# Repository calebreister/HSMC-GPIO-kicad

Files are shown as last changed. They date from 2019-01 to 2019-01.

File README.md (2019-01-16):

# HSMC-GPIO-kicad

This is a project created to test my new [HSMC Card KiCad footprints](https://github.com/KiCad/kicad-footprints/pulls?page=1&q=is%3Apr+is%3Aopen). It is based loosely on the [Terasis HSTC-GPIO Card](https://www.terasic.com.tw/cgi-bin/page/archive.pl?Language=English&No=322). In small quantities, the cost is comparable to the HSTC-GPIO Card.

## Features
- 40 GPIO pins
- Protection diodes and series resistors
- Power supply terminals
- Buffered I2C port with selectable voltage

## License
<br /><span xmlns:dct="http://purl.org/dc/terms/" property="dct:title">HSMC-GPIO-kicad</span> by <a xmlns:cc="http://creativecommons.org/ns#" href="https://github.com/calebreister/" property="cc:attributionName" rel="cc:attributionURL">Caleb Reister</a> is licensed under a <a rel="license" href="http://creativecommons.org/licenses/by-sa/4.0/">Creative Commons Attribution-ShareAlike 4.0 International License</a>.

## Pictures
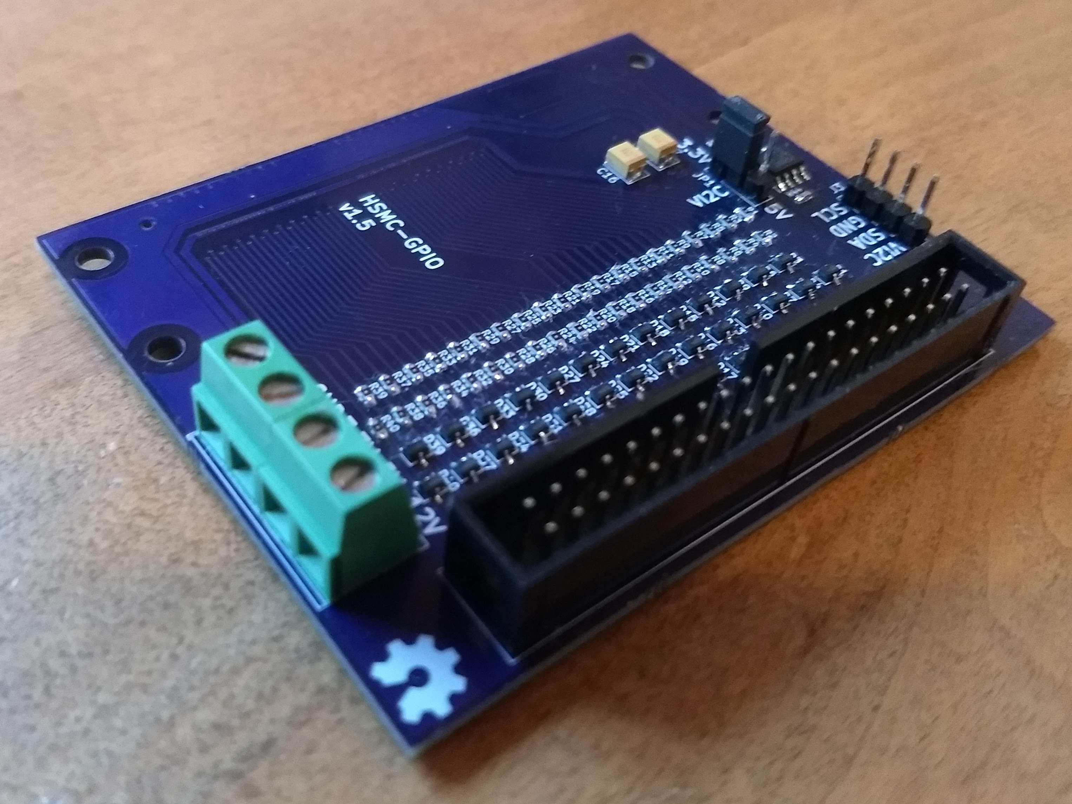
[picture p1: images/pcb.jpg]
Assembled PCB


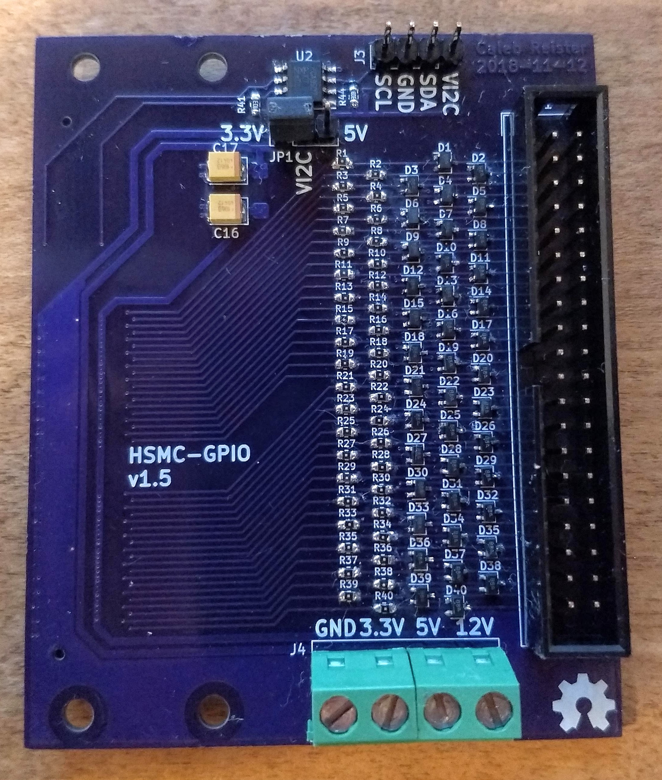
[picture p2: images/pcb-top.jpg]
PCB Top


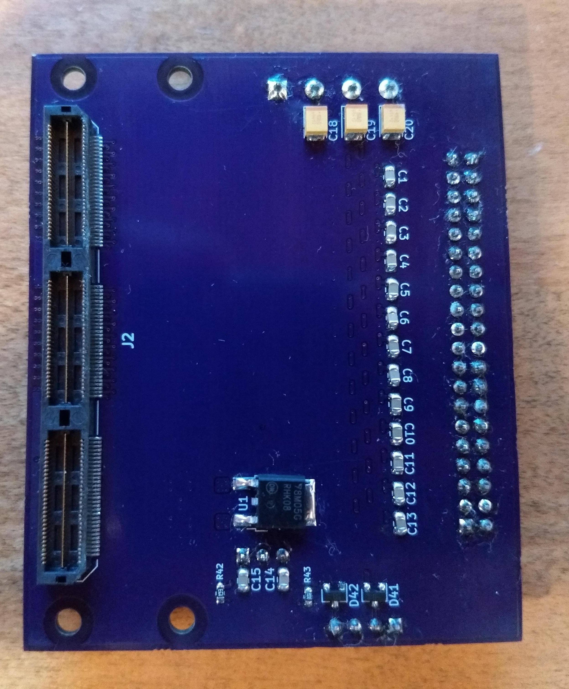
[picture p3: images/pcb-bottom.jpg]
PCB Bottom


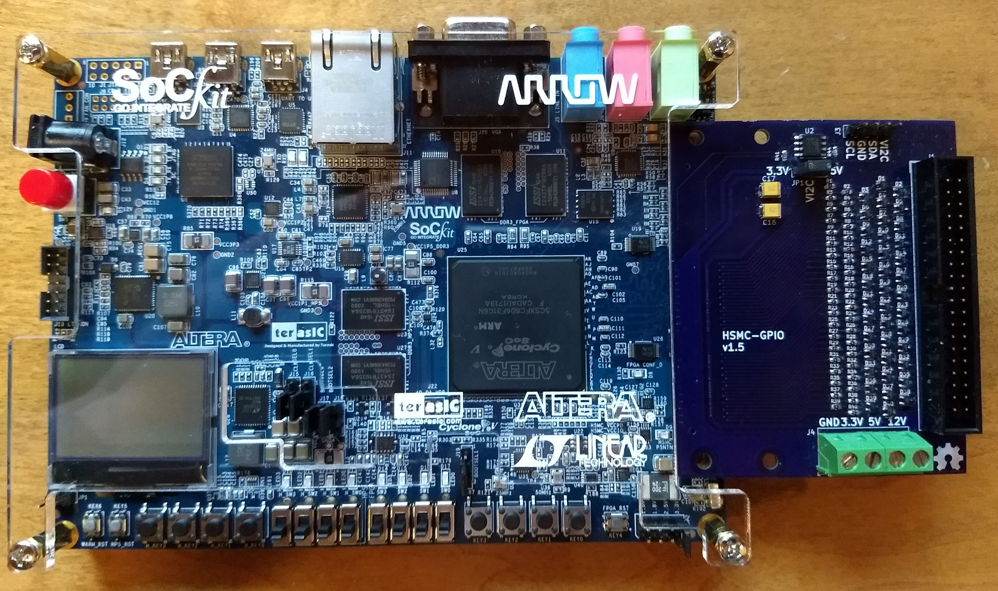
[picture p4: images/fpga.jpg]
PCB Attached to an FPGA board


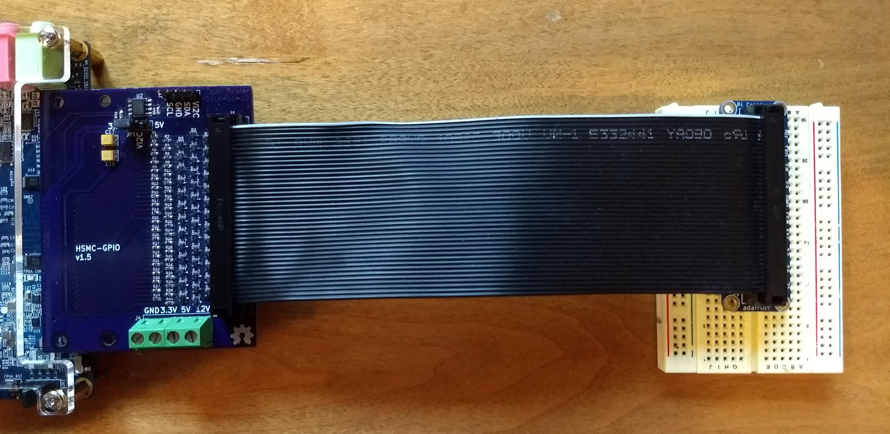
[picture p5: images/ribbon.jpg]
40-pin ribbon cable


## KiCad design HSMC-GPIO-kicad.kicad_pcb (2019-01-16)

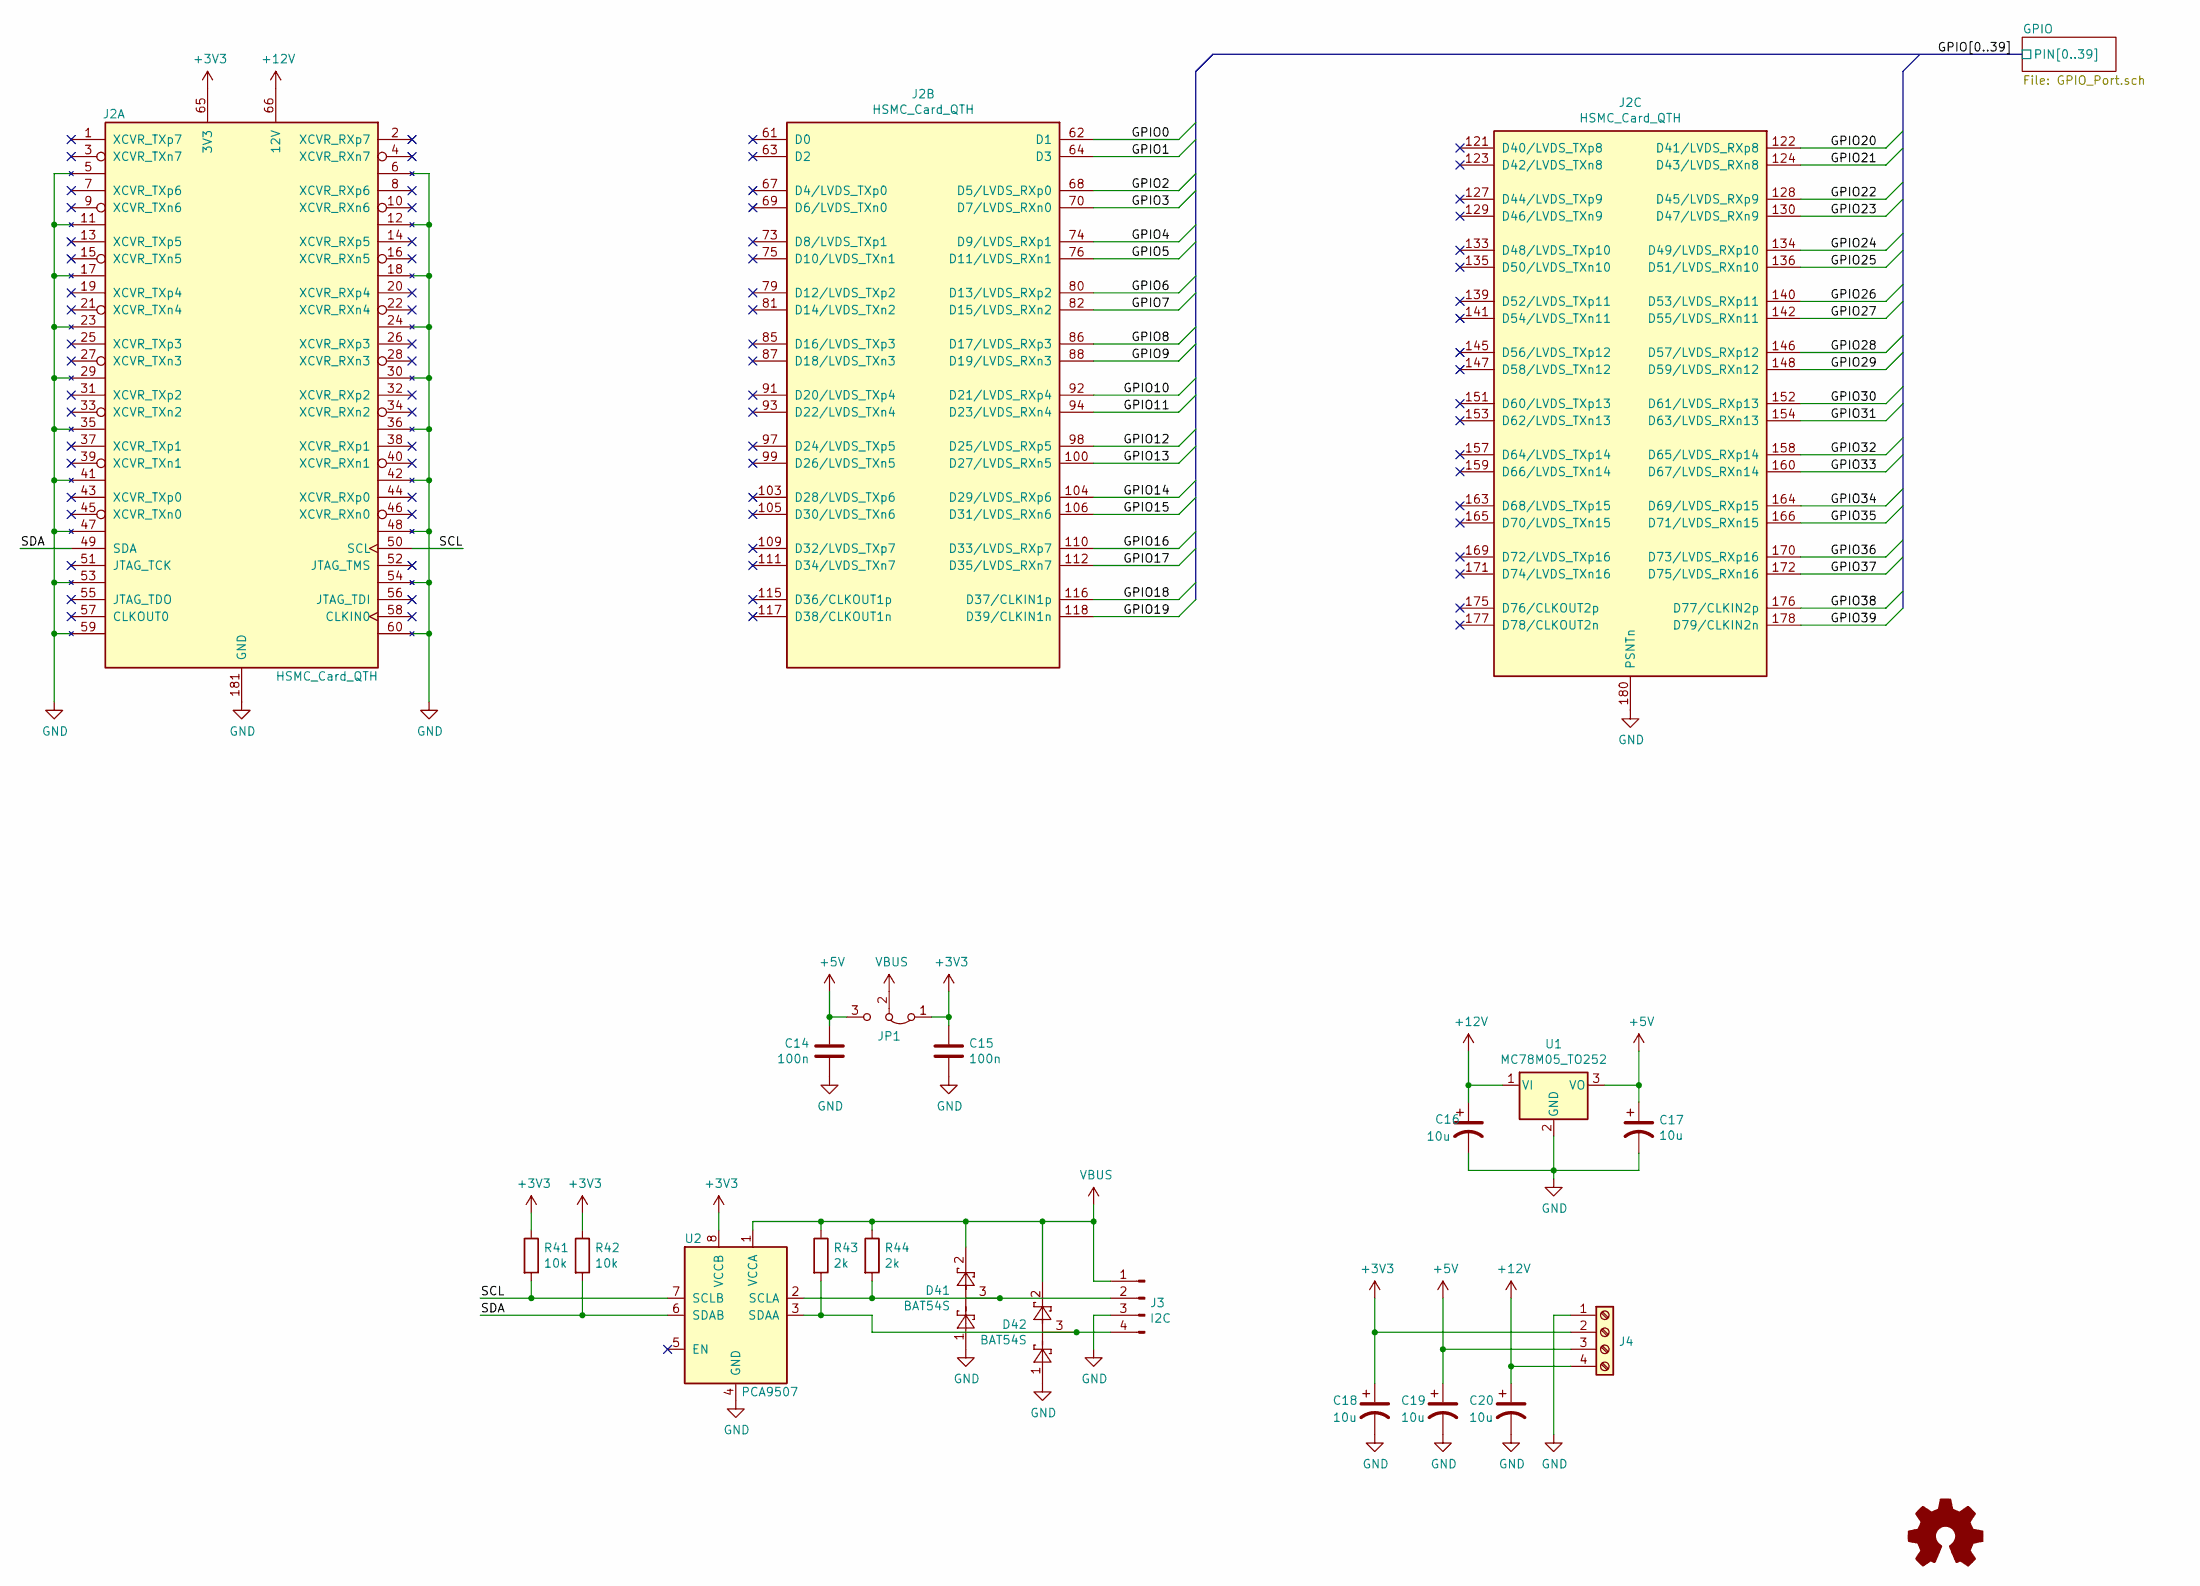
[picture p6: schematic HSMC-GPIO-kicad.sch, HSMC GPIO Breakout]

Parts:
C14, C15: 100n; C_0805_2012Metric
C16, C17, C18, C19, C20: 10u; CP_EIA-3528-21_Kemet-B
D41, D42: BAT54S; SOT-23
J2: HSMC_Card_QTH; Samtec_HSMC_Card_QTH-090-01-x-D-A_3.076x0.932in_P0.5mm_Vert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
J3: I2C; PinHeader_1x04_P2.54mm_Vertical
J4: Screw_Terminal_01x04; TerminalBlock_bornier-4_P5.08mm
JP1: Jumper_3_Bridged12; PinHeader_1x03_P2.54mm_Vertical
LOGO1: Logo_Open_Hardware_Small; OSHW-Symbol_6.7x6mm_SilkScreen
R41, R42: 10k; R_0603_1608Metric
R43, R44: 2k; R_0603_1608Metric
U1: MC78M05_TO252; TO-252-2
U2: PCA9507; SOIC-8_3.9x4.9mm_P1.27mm

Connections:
+3V3: C15.2, C18.1, J2.65 (3V3), J2.71 (3V3), J2.77 (3V3), J2.83 (3V3), J2.89 (3V3), J2.95 (3V3), J2.101 (3V3), J2.107 (3V3), J2.113 (3V3), J2.119 (3V3), J2.125 (3V3), J2.131 (3V3), J2.137 (3V3), J2.143 (3V3), J2.149 (3V3), J2.155 (3V3), J2.161 (3V3), J2.167 (3V3), J2.173 (3V3), J2.179 (3V3), J4.2, JP1.1 (A), R41.1, R42.1, U2.8 (VCCB); also elsewhere on the board
+5V: C14.2, C17.1, C19.1, J4.3, JP1.3 (B), U1.3 (VO)
+12V: C16.1, C20.1, J2.66 (12V), J2.72 (12V), J2.78 (12V), J2.84 (12V), J2.90 (12V), J2.96 (12V), J2.102 (12V), J2.108 (12V), J2.114 (12V), J2.120 (12V), J2.126 (12V), J2.132 (12V), J2.138 (12V), J2.144 (12V), J2.150 (12V), J2.156 (12V), J2.162 (12V), J2.168 (12V), J2.174 (12V), J4.4, U1.1 (VI)
/GPIO0: J2.62 (D1); also elsewhere on the board
/GPIO1: J2.64 (D3); also elsewhere on the board
/GPIO2: J2.68 (D5/LVDS_RXp0); also elsewhere on the board
/GPIO3: J2.70 (D7/LVDS_RXn0); also elsewhere on the board
/GPIO4: J2.74 (D9/LVDS_RXp1); also elsewhere on the board
/GPIO5: J2.76 (D11/LVDS_RXn1); also elsewhere on the board
/GPIO6: J2.80 (D13/LVDS_RXp2); also elsewhere on the board
/GPIO7: J2.82 (D15/LVDS_RXn2); also elsewhere on the board
/GPIO8: J2.86 (D17/LVDS_RXp3); also elsewhere on the board
/GPIO9: J2.88 (D19/LVDS_RXn3); also elsewhere on the board
/GPIO10: J2.92 (D21/LVDS_RXp4); also elsewhere on the board
/GPIO11: J2.94 (D23/LVDS_RXn4); also elsewhere on the board
/GPIO12: J2.98 (D25/LVDS_RXp5); also elsewhere on the board
/GPIO13: J2.100 (D27/LVDS_RXn5); also elsewhere on the board
/GPIO14: J2.104 (D29/LVDS_RXp6); also elsewhere on the board
/GPIO15: J2.106 (D31/LVDS_RXn6); also elsewhere on the board
/GPIO16: J2.110 (D33/LVDS_RXp7); also elsewhere on the board
/GPIO17: J2.112 (D35/LVDS_RXn7); also elsewhere on the board
/GPIO18: J2.116 (D37/CLKIN1p); also elsewhere on the board
/GPIO19: J2.118 (D39/CLKIN1n); also elsewhere on the board
/GPIO20: J2.122 (D41/LVDS_RXp8); also elsewhere on the board
/GPIO21: J2.124 (D43/LVDS_RXn8); also elsewhere on the board
/GPIO22: J2.128 (D45/LVDS_RXp9); also elsewhere on the board
/GPIO23: J2.130 (D47/LVDS_RXn9); also elsewhere on the board
/GPIO24: J2.134 (D49/LVDS_RXp10); also elsewhere on the board
/GPIO25: J2.136 (D51/LVDS_RXn10); also elsewhere on the board
/GPIO26: J2.140 (D53/LVDS_RXp11); also elsewhere on the board
/GPIO27: J2.142 (D55/LVDS_RXn11); also elsewhere on the board
/GPIO28: J2.146 (D57/LVDS_RXp12); also elsewhere on the board
/GPIO29: J2.148 (D59/LVDS_RXn12); also elsewhere on the board
/GPIO30: J2.152 (D61/LVDS_RXp13); also elsewhere on the board
/GPIO31: J2.154 (D63/LVDS_RXn13); also elsewhere on the board
/GPIO32: J2.158 (D65/LVDS_RXp14); also elsewhere on the board
/GPIO33: J2.160 (D67/LVDS_RXn14); also elsewhere on the board
/GPIO34: J2.164 (D69/LVDS_RXp15); also elsewhere on the board
/GPIO35: J2.166 (D71/LVDS_RXn15); also elsewhere on the board
/GPIO36: J2.170 (D73/LVDS_RXp16); also elsewhere on the board
/GPIO37: J2.172 (D75/LVDS_RXn16); also elsewhere on the board
/GPIO38: J2.176 (D77/CLKIN2p); also elsewhere on the board
/GPIO39: J2.178 (D79/CLKIN2n); also elsewhere on the board
/SCL: J2.50 (SCL), R41.2, U2.7 (SCLB)
/SDA: J2.49 (SDA), R42.2, U2.6 (SDAB)
GND: C14.1, C15.1, C16.2, C17.2, C18.2, C19.2, C20.2, D41.1, D42.1, J2.5, J2.6, J2.11, J2.12, J2.17, J2.18, J2.23, J2.24, J2.29, J2.30, J2.35, J2.36, J2.41, J2.42, J2.47, J2.48, J2.53, J2.54, J2.59, J2.60, J2.180 (PSNTn), J2.181 (GND), J2.182 (GND), J2.183 (GND), J2.184 (GND), J2.185 (GND), J2.186 (GND), J2.187 (GND), J2.188 (GND), J2.189 (GND), J2.190 (GND), J2.191 (GND), J2.192 (GND), J3.3, J4.1, U1.2 (GND), U2.4 (GND); also elsewhere on the board
unnamed: D41.3, J3.2, R44.2, U2.2 (SCLA)
unnamed: D42.3, J3.4, R43.2, U2.3 (SDAA)
VBUS: D41.2, D42.2, J3.1, JP1.2 (C), R43.1, R44.1, U2.1 (VCCA)

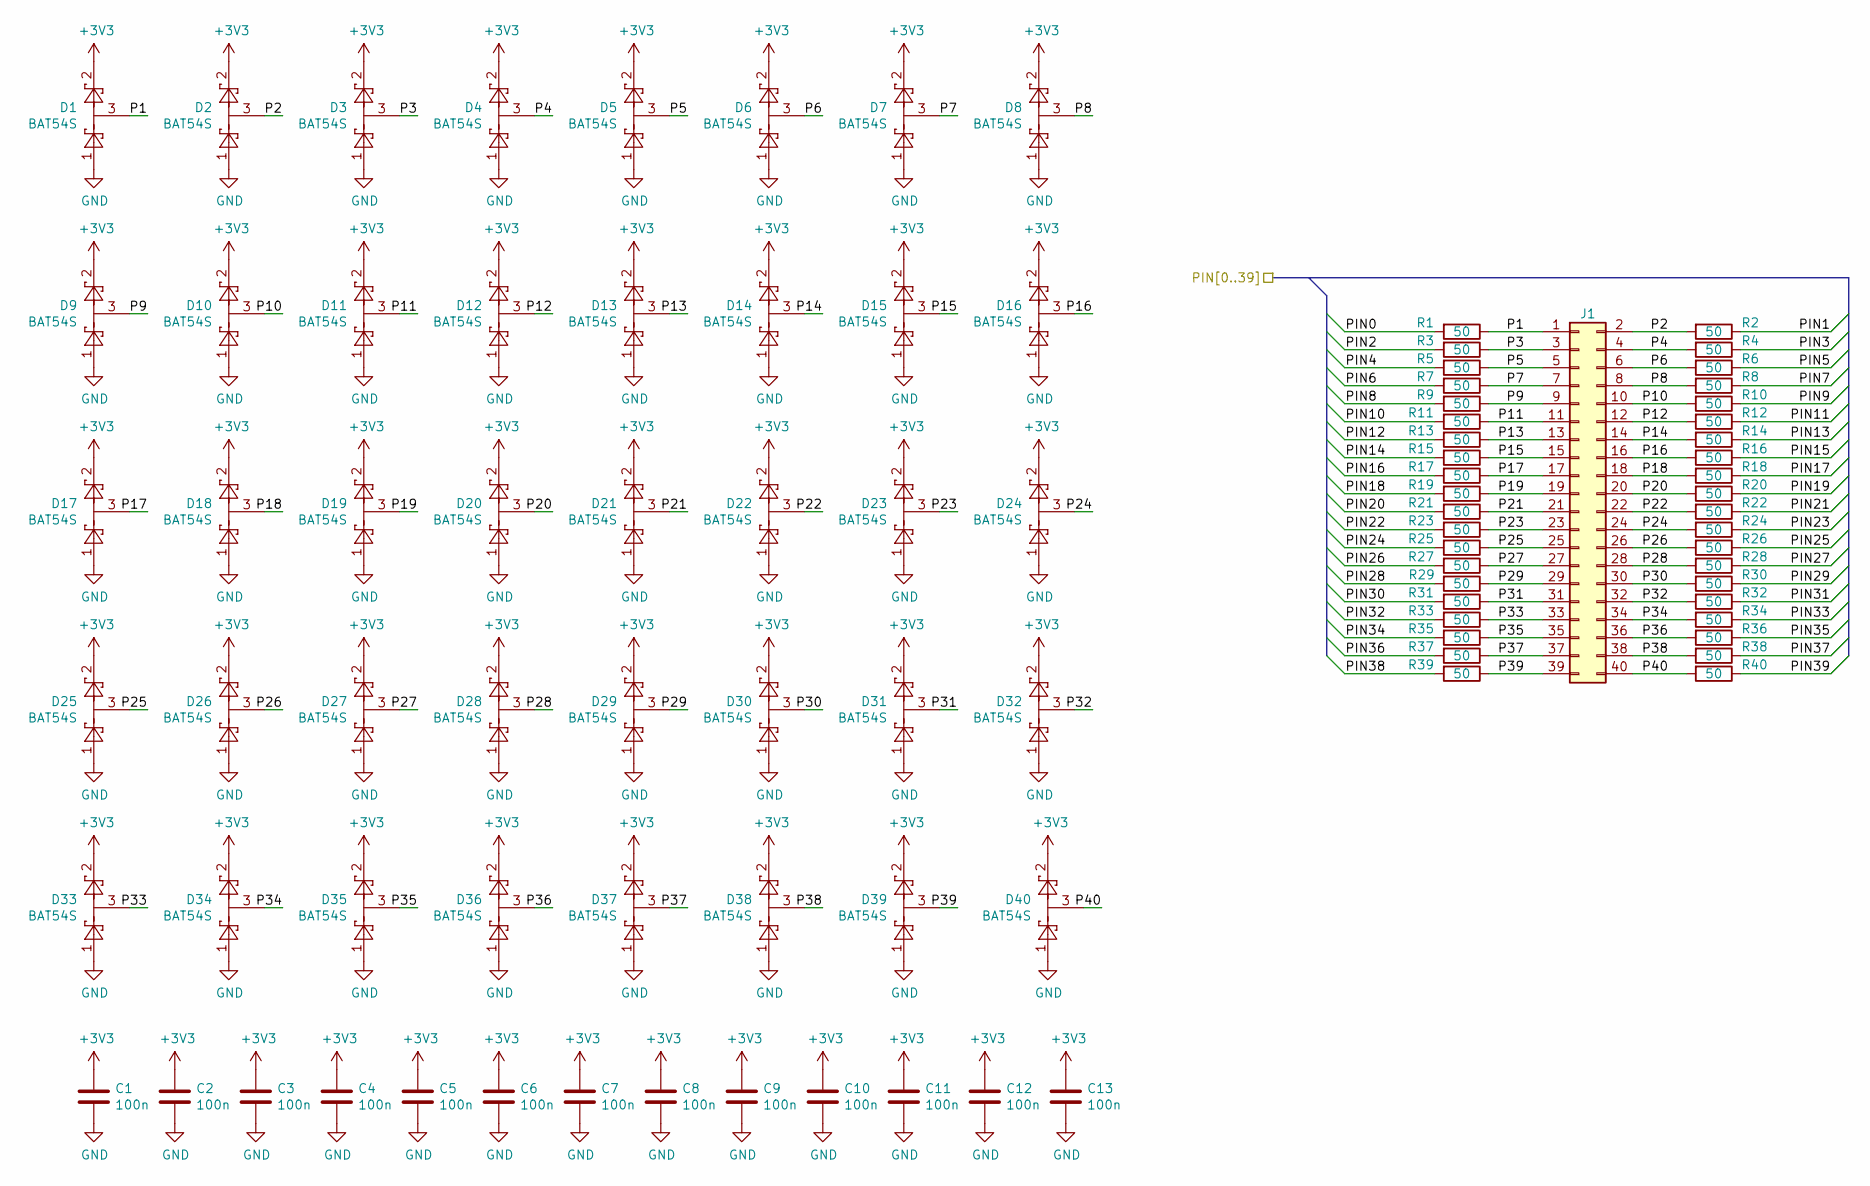
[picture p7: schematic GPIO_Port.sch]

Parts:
C1, C2, C3, C4, C5, C6, C7, C8, C9, C10, C11, C12, C13: 100n; C_0805_2012Metric
D1, D2, D3, D4, D5, D6, D7, D8, D9, D10, D11, D12, D13, D14, D15, D16, D17, D18, D19, D20, D21, D22, D23, D24, D25, D26, D27, D28, D29, D30, D31, D32, D33, D34, D35, D36, D37, D38, D39, D40: BAT54S; SOT-323_SC-70
J1: Conn_02x20_Odd_Even; IDC-Header_2x20_P2.54mm_Vertical
R1, R2, R3, R4, R5, R6, R7, R8, R9, R10, R11, R12, R13, R14, R15, R16, R17, R18, R19, R20, R21, R22, R23, R24, R25, R26, R27, R28, R29, R30, R31, R32, R33, R34, R35, R36, R37, R38, R39, R40: 50; R_0603_1608Metric

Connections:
+3V3: C1.1, C2.1, C3.1, C4.1, C5.1, C6.1, C7.1, C8.1, C9.1, C10.1, C11.1, C12.1, C13.1, D1.2, D2.2, D3.2, D4.2, D5.2, D6.2, D7.2, D8.2, D9.2, D10.2, D11.2, D12.2, D13.2, D14.2, D15.2, D16.2, D17.2, D18.2, D19.2, D20.2, D21.2, D22.2, D23.2, D24.2, D25.2, D26.2, D27.2, D28.2, D29.2, D30.2, D31.2, D32.2, D33.2, D34.2, D35.2, D36.2, D37.2, D38.2, D39.2, D40.2; also elsewhere on the board
/GPIO0: R1.2; also elsewhere on the board
/GPIO1: R2.1; also elsewhere on the board
/GPIO2: R3.2; also elsewhere on the board
/GPIO3: R4.1; also elsewhere on the board
/GPIO4: R5.2; also elsewhere on the board
/GPIO5: R6.1; also elsewhere on the board
/GPIO6: R7.2; also elsewhere on the board
/GPIO7: R8.1; also elsewhere on the board
/GPIO8: R9.2; also elsewhere on the board
/GPIO9: R10.1; also elsewhere on the board
/GPIO10: R11.2; also elsewhere on the board
/GPIO11: R12.1; also elsewhere on the board
/GPIO12: R13.2; also elsewhere on the board
/GPIO13: R14.1; also elsewhere on the board
/GPIO14: R15.2; also elsewhere on the board
/GPIO15: R16.1; also elsewhere on the board
/GPIO16: R17.2; also elsewhere on the board
/GPIO17: R18.1; also elsewhere on the board
/GPIO18: R19.2; also elsewhere on the board
/GPIO19: R20.1; also elsewhere on the board
/GPIO20: R21.2; also elsewhere on the board
/GPIO21: R22.1; also elsewhere on the board
/GPIO22: R23.2; also elsewhere on the board
/GPIO23: R24.1; also elsewhere on the board
/GPIO24: R25.2; also elsewhere on the board
/GPIO25: R26.1; also elsewhere on the board
/GPIO26: R27.2; also elsewhere on the board
/GPIO27: R28.1; also elsewhere on the board
/GPIO28: R29.2; also elsewhere on the board
/GPIO29: R30.1; also elsewhere on the board
/GPIO30: R31.2; also elsewhere on the board
/GPIO31: R32.1; also elsewhere on the board
/GPIO32: R33.2; also elsewhere on the board
/GPIO33: R34.1; also elsewhere on the board
/GPIO34: R35.2; also elsewhere on the board
/GPIO35: R36.1; also elsewhere on the board
/GPIO36: R37.2; also elsewhere on the board
/GPIO37: R38.1; also elsewhere on the board
/GPIO38: R39.2; also elsewhere on the board
/GPIO39: R40.1; also elsewhere on the board
/GPIO/P1: D1.3, J1.1, R1.1
/GPIO/P2: D2.3, J1.2, R2.2
/GPIO/P3: D3.3, J1.3, R3.1
/GPIO/P4: D4.3, J1.4, R4.2
/GPIO/P5: D5.3, J1.5, R5.1
/GPIO/P6: D6.3, J1.6, R6.2
/GPIO/P7: D7.3, J1.7, R7.1
/GPIO/P8: D8.3, J1.8, R8.2
/GPIO/P9: D9.3, J1.9, R9.1
/GPIO/P10: D10.3, J1.10, R10.2
/GPIO/P11: D11.3, J1.11, R11.1
/GPIO/P12: D12.3, J1.12, R12.2
/GPIO/P13: D13.3, J1.13, R13.1
/GPIO/P14: D14.3, J1.14, R14.2
/GPIO/P15: D15.3, J1.15, R15.1
/GPIO/P16: D16.3, J1.16, R16.2
/GPIO/P17: D17.3, J1.17, R17.1
/GPIO/P18: D18.3, J1.18, R18.2
/GPIO/P19: D19.3, J1.19, R19.1
/GPIO/P20: D20.3, J1.20, R20.2
/GPIO/P21: D21.3, J1.21, R21.1
/GPIO/P22: D22.3, J1.22, R22.2
/GPIO/P23: D23.3, J1.23, R23.1
/GPIO/P24: D24.3, J1.24, R24.2
/GPIO/P25: D25.3, J1.25, R25.1
/GPIO/P26: D26.3, J1.26, R26.2
/GPIO/P27: D27.3, J1.27, R27.1
/GPIO/P28: D28.3, J1.28, R28.2
/GPIO/P29: D29.3, J1.29, R29.1
/GPIO/P30: D30.3, J1.30, R30.2
/GPIO/P31: D31.3, J1.31, R31.1
/GPIO/P32: D32.3, J1.32, R32.2
/GPIO/P33: D33.3, J1.33, R33.1
/GPIO/P34: D34.3, J1.34, R34.2
/GPIO/P35: D35.3, J1.35, R35.1
/GPIO/P36: D36.3, J1.36, R36.2
/GPIO/P37: D37.3, J1.37, R37.1
/GPIO/P38: D38.3, J1.38, R38.2
/GPIO/P39: D39.3, J1.39, R39.1
/GPIO/P40: D40.3, J1.40, R40.2
GND: C1.2, C2.2, C3.2, C4.2, C5.2, C6.2, C7.2, C8.2, C9.2, C10.2, C11.2, C12.2, C13.2, D1.1, D2.1, D3.1, D4.1, D5.1, D6.1, D7.1, D8.1, D9.1, D10.1, D11.1, D12.1, D13.1, D14.1, D15.1, D16.1, D17.1, D18.1, D19.1, D20.1, D21.1, D22.1, D23.1, D24.1, D25.1, D26.1, D27.1, D28.1, D29.1, D30.1, D31.1, D32.1, D33.1, D34.1, D35.1, D36.1, D37.1, D38.1, D39.1, D40.1; also elsewhere on the board

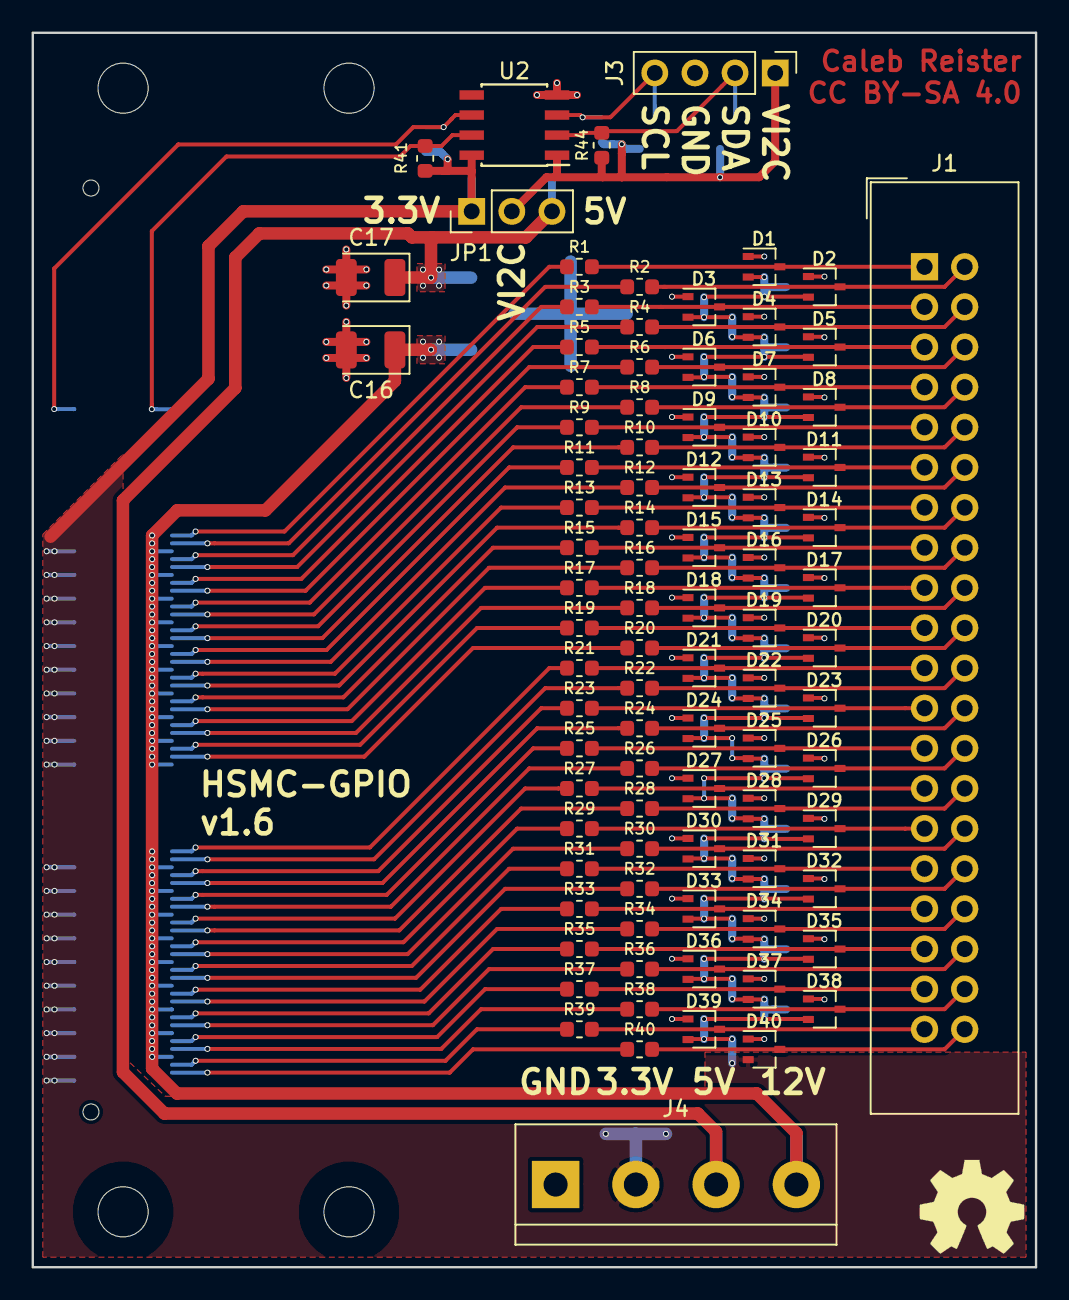
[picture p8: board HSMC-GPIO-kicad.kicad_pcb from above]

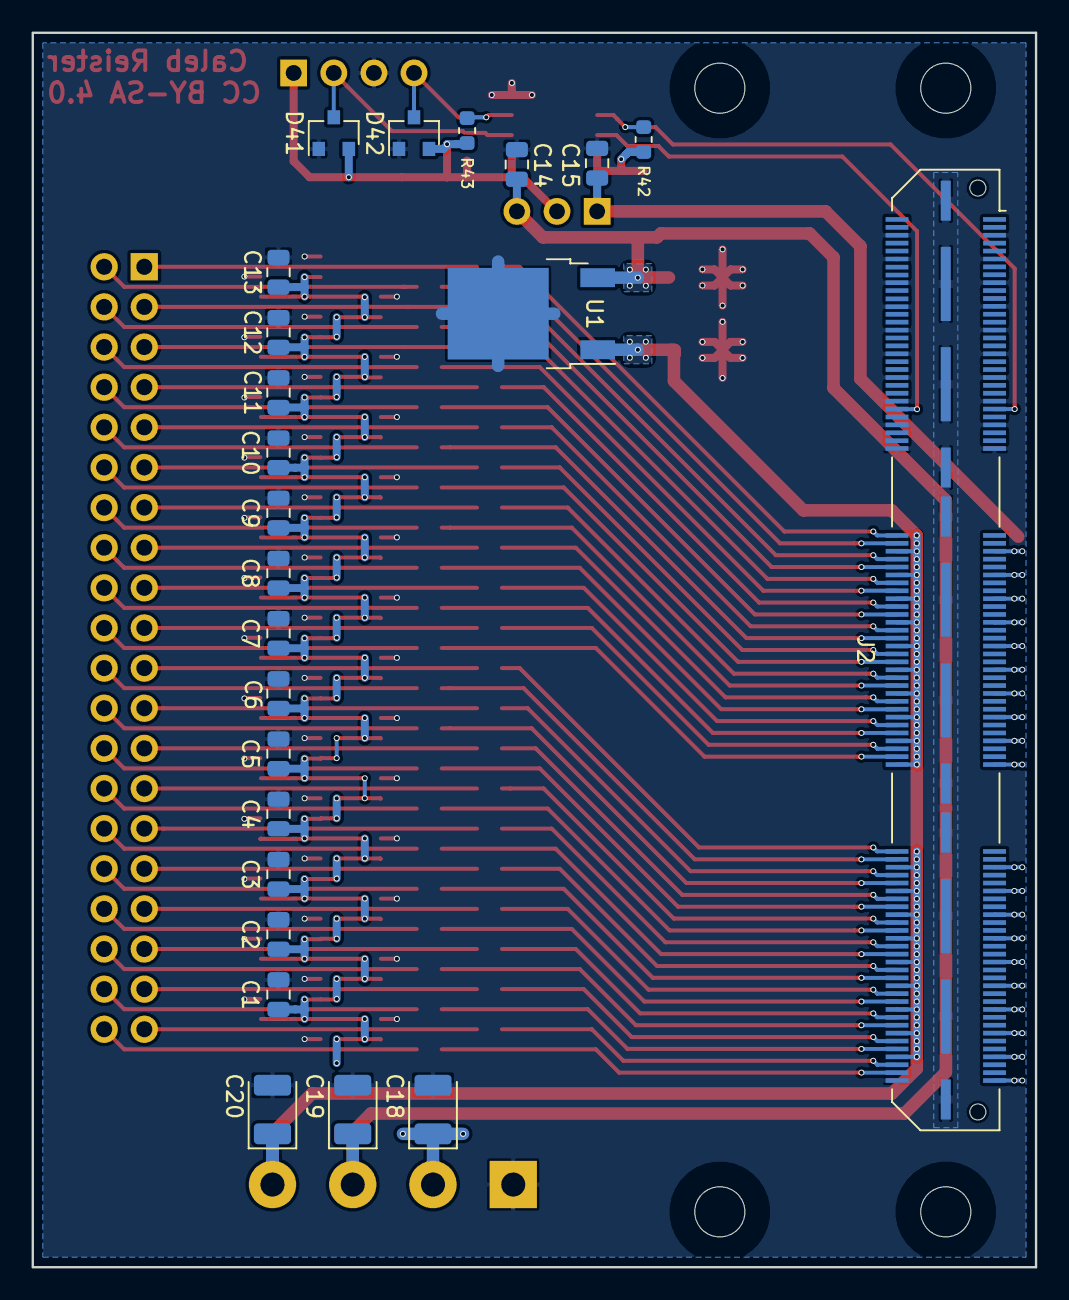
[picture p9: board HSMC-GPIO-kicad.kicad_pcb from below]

Board: 2 copper layers, 63.5 x 78.1 mm, 114 parts (24 on the bottom side), 89 nets.

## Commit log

2018-09-12 Finish initial schematic, work on PCB design
    [GPIO_Port.sch, HSMC-GPIO-kicad.kicad_pcb, HSMC-GPIO-kicad.sch]
2018-09-12 Reroute ribbon connector protection circuitry, switch to single ribbon cable configuration.
    [GPIO_Port.sch, HSMC-GPIO-kicad.kicad_pcb, HSMC-GPIO-kicad.sch]
2018-09-13 Change pin/bus labels in schematic
    [GPIO_Port.sch, HSMC-GPIO-kicad.kicad_pcb, HSMC-GPIO-kicad.sch]
2018-09-14 Begin routing ribbon cable connector
    [GPIO_Port.sch, HSMC-GPIO-kicad.kicad_pcb, HSMC-GPIO-kicad.sch]
2018-09-14 Continue routing GPIO ribbon connector
    [HSMC-GPIO-kicad.kicad_pcb, HSMC-GPIO-kicad.sch]
2018-09-15 Finish routing GPIO port
    [GPIO_Port.sch, HSMC-GPIO-kicad.kicad_pcb, HSMC-GPIO-kicad.sch]
2018-09-15 Adjust board and plane sizes
    [HSMC-GPIO-kicad.kicad_pcb]
2018-09-20 Finish initial placement and routing
    [HSMC-GPIO-kicad.kicad_pcb, HSMC-GPIO-kicad.sch]
2018-09-20 Fix major error in HSMC footprints
    [HSMC-GPIO-kicad.kicad_pcb]
2018-09-20 Reroute GPIO pins (again)
    [HSMC-GPIO-kicad.kicad_pcb, HSMC-GPIO-kicad.sch]
2018-09-20 Change BAT54S diode packages back to to SOT-23
    [GPIO_Port.sch, HSMC-GPIO-kicad.kicad_pcb, HSMC-GPIO-kicad.sch]
2018-09-21 Fix issues and reroute I2C buffer, length match GPIO bus
    [HSMC-GPIO-kicad.kicad_pcb, HSMC-GPIO-kicad.sch]
2018-09-22 Rotate GPIO connector 180deg, reroute
    [HSMC-GPIO-kicad.kicad_pcb, HSMC-GPIO-kicad.sch]
2018-09-22 Clean-up, generate Gerber & drill files
    [HSMC-GPIO-kicad-B.Adhes.gbr, HSMC-GPIO-kicad-B.Cu.gbr, HSMC-GPIO-kicad-B.Mask.gbr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]
2018-10-02 Modify and submit to Sunstone for DFM report.
    [HSMC-GPIO-kicad-B.Adhes.gbr, HSMC-GPIO-kicad-B.Cu.gbr, HSMC-GPIO-kicad-B.Mask.gbr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]
2018-10-02 Re-place protection diodes/resistors, change diode packages to SOT-323
    [HSMC-GPIO-kicad.kicad_pcb]
2018-10-08 Reroute GPIO, 5V regulator, and I2C buffer
    [GPIO_Port.sch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]
2018-10-15 Minor footprint and position adjustments
    [HSMC-GPIO-kicad-B.Adhes.gbr, HSMC-GPIO-kicad-B.Cu.gbr, HSMC-GPIO-kicad-B.Mask.gbr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]
2018-10-22 Modify board to meet OSH Park specs, remove old HSMC card library.
    [HSMC-GPIO-kicad-B.Adhes.gbr, HSMC-GPIO-kicad-B.Cu.gbr, HSMC-GPIO-kicad-B.Mask.gbr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]
2018-11-13 Change to 5.08mm power terminal, other minor modifications.
    [HSMC-GPIO-kicad-B.Cu.gbr, HSMC-GPIO-kicad-B.Mask.gbr, HSMC-GPIO-kicad-B.SilkS.gbr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]
2019-01-16 Updated to use new KLC-compliant symbols and footprints
    [GPIO_Port.sch, HSMC-GPIO-kicad.kicad_pcb, HSMC-GPIO-kicad.sch]
2019-01-16 Add license to PCB and increment version number
    [HSMC-GPIO-kicad.kicad_pcb]
2019-01-16 Update fabrication outputs to v1.6.
    [HSMC-GPIO-kicad-B.Cu.gbr, HSMC-GPIO-kicad-B.Mask.gbr, HSMC-GPIO-kicad-B.SilkS.gbr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]

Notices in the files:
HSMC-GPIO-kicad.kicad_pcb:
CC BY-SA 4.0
